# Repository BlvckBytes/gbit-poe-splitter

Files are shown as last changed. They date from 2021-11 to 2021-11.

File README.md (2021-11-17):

# gbit-poe-splitter

Power devices which don't support PoE and fine-adjust the received voltage at the same time. This equipment conforms to the *802.3at* standard, also known as *PoE+*.

⚠️ Use at your own risk and always properly test the product before connecting expensive gear up to it!

## Table of Contents

* [Goals](#goals)
* [The Product](#the-product)
* [Introduction](#introduction)
  * [802\.3af (PoE)](#8023af-poe)
  * [802\.3at (PoE\+)](#8023at-poe)
  * [802\.3bt (Hi\-PoE, PoE\+\+)](#8023bt-hi-poe-poe)
* [Concept](#concept)
* [Features](#features)
  * [Ports](#ports)
  * [Settings](#settings)
  * [Status LEDs](#status-leds)
* [Parts](#parts)
* [Prototyping](#prototyping)
  * [Summary](#summary)

## Goals

* ✅ Small footprint PCB
* ✅ Max budget of 15 Euros
* ✅ Support up to 60V of input
* ✅ Selectable output voltage
* ✅ Selectable PoE class
* ✅ Highest possible current throughput
* ✅ Indication of active type 2
* ✅ DC Output Jack
* ✅ Proper centertap-termination

## The Product

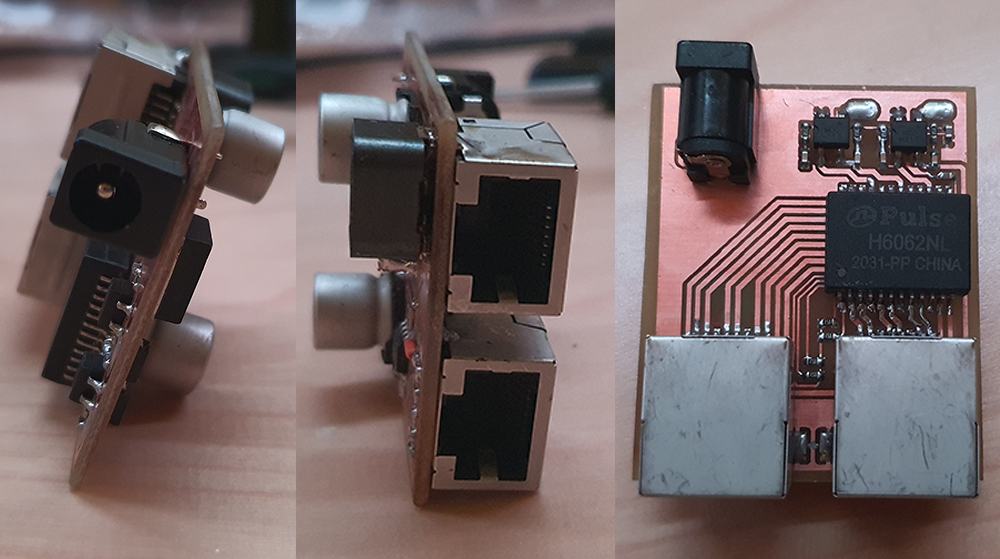
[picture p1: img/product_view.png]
Product View


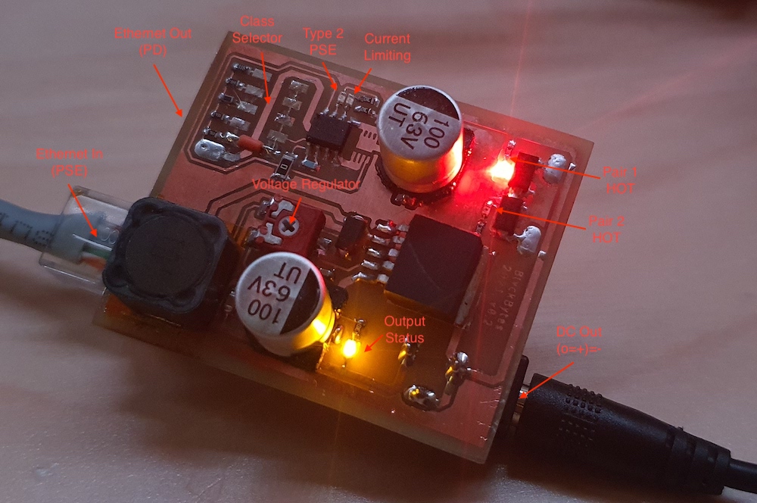
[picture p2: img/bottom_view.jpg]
Bottom View


## Introduction

PoE is short for *Power over Ethernet* and will allow to transmit the needed power for devices on the other end of the CAT-X cable. This is especially of interest for already existing infrastructure, where it's just not economical to run a separate power wire. The only drawbacks are that there's a limit to how much energy can be transmitted and that you might experience a voltage-drop and thus an energy-loss over longer distances of wire.

### 802.3af (PoE)

This standard adds power-delivery to *802.3*, with up to *15.4W* at the output of the power sourcing equipment (PSE), using two twisted-pairs for injection. After calculating the average real world losses over the wire , the consumer only receives around *12.95W* of power. There are also lower power-classes, which are not the default and need to be registered for by the powered device (PD) explicitely.

| Class | Min Power (at PD, [W]) | Max Power (at PD, [W]) |
|:---|:---|:---|
| 0 | 0.44 | 12.95 |
| 1 | 0.44 | 3.84 |
| 2 | 3.84 | 6.49 |
| 3 | 6.49 | 12.95 |

### 802.3at (PoE+)

Since *802.3af* is not sufficient for some standard usecases, *802.3at* bumps it up a notch, while still using only two twisted-pairs. Now, PDs can receive up to *25.5W*, which should be plenty for switches, access-points, VOIP, card-readers and so on and so forth.

| Class | Min Power (at PD, [W]) | Max Power (at PD, [W]) |
|:---|:---|:---|
| 4 | 12.95 | 25.5 |

### 802.3bt (Hi-PoE, PoE++)

In order to meet the higher demand of power in special cases, IEEE came up with this standard at the end of 2018. Instead of two pairs, it uses all four pairs for power delivery, which will allow up to **100 watts**. Power loss gets cut in half, at least in theory. Since this standard requires more expensive technology, it's not covered by this project.

## Concept

There are several [requirements](https://www.ieee802.org/3/poep_study//email/pdf00005.pdf) to the PD, if it wants to consume *802.3at*.

The main component is represented by the [H6062NL](https://eu.mouser.com/ProductDetail/Pulse-Electronics/H6062NL?qs=hlTQ6wBu%252Bnnq8WII%2F92SGQ%3D%3D), which is a signal transformer that supports up to *1000Base-T*. It consits of four individual isolation transformers, which offer a center-tap for power delivery purposes, where one transformer corresponds to one twisted pair, to fully isolate the PD.

In order to support detection, classification, inrush-current limiting and short-circuit protection, I decided on the [TPS2379](https://www.ti.com/lit/ds/symlink/tps2379.pdf?ts=1636211997743&ref_url=https%253A%252F%252Fwww.google.com%252F). It supports up to *1A* of operating current, which should be plenty, and can even be extended using an external mosfet.

To tap the available power from either one of the two pairs, and to handle reverse-polarity situations, two full bridge rectifiers are inserted directly inbetween the transformers and the control-IC. The output voltage will then be fed through a buck-converter, to easily regulate it. [LM2596HV](http://hmsemi.com/downfile/LM2596HV.PDF) seems to be a perfect fit for this job.

### Detection

The PSE constantly pulses a 4-point detection signal on the port in question, which starts out `LOW` and then rises `HIGH` two times. With the known voltage potential, and the measurable current draw, the PSE calculates the inner resistance of the connected PD. It has to `23.75kOhm < R < 26.25kOhm`, to be a valid PoE device.

### Classification

After passing detection, the PD has to specify it's desired power class to the PSE. The PSE sends signals between 14.5V and 20.5V, while the PD removes R_DET from the line and applies R_CLS, in series with a constant 2.5V regulator. This way, the PSE can accurately measure the current flowing through R_CLS, and thus determine the desired class.

After completing both steps successfully, power is activated.

## Features

### Ports

* Ethernet in (from PSE)
* Ethernet out (to non-PD)
* Standard DC-jack to supply power

### Settings

* 5 positions for class 0-4
* Voltage regulation potentiometer

### Status LEDs

* Power available (Yellow)
* Inrush current limiting (Yellow)
* Type 2 active (Yellow)
* Pair 1 & 2 hot (Red)
* Pair 3 & 4 hot (Red)

## Parts

| Part | Description | Shop | Price/Pice | Amount | Total |
|:-----|:---|:-----|:---|:---|:---|
| **Integrated Circuits** |
| H6062NL | Signal Transformer | Mouser | 4.27€ | 1 | 4.27€ |
| TPS2379 | 802.3af PD Interface | Mouser | 2.35€ | 1 | 2.35€ |
| MB1S-TP | Bridge Rectifier | Mouser | 0.26€ | 2 | 0.52€ |
| LM2596HV | [Regulator & aux. Components](https://de.aliexpress.com/item/32916300929.html?spm=a2g0s.9042311.0.0.55414c4dqviJXF) | AliExpress | 1.12€ | 1 | 1.12€ |
| SI7454FDP-T1-RE3 | N-Channel Mosfet | Mouser | 0.69€ | 1 | 0.69€ |
| **Connectors** |
| RJLSE4118101 | RJ45 8P8C Shielded | Mouser | 0.91€ | 2 | 1.82€ |
| PRT-10811 | 5.5mm DC Jack | Mouser | 0.81€ | 1 | 0.81€ |
| **Status LEDs** |
| CRCW060310K0FKTC | 10k Ohm 0603 | Mouser | 0.022€ | 5 | 0.11€ |
| 150060GS75000 | LED Yellow 0603 | Mouser | 0.12€ | 3 | 0.24€ |
| 150060GS75000 | LED Red 0603 | Mouser | 0.12€ | 2 | 0.24€ |
| **Filtering & Termination** |
| RC0603FR-0775RL | 75 Ohm 0603 | Mouser | 0.006€ | 8 | 0.012€ |
| CL10B103KO8NNNC | 10nF 0603 | Mouser | 0.011€ | 4 | 0.044€ |
| C0805C104K8RACAUTO | 100nF 0805 | Mouser | 0.058€ | 1 | 0.058€ |
| CL10C102JB8NNND | 1nF 0603 | Mouser | 0.016€ | 2 | 0.032€ |
| **PoE Class (R_CLS)** |
| RC0603FR-071K27L | 1.27k Ohm 0603 | Mouser | 0.008€ | 1 | 0.008€ |
| CR0603-FX-2430ELF | 243 Ohm 0603 | Mouser | 0.016€ | 1 | 0.016€ |
| ERJ-3EKF1370V | 137 Ohm 0603 | Mouser | 0.014€ | 2 | 0.014€ |
| CR0603-FX-90R9ELF | 90.9 Ohm 0603 | Mouser | 0.013€ | 1 | 0.013€ |
| CR0603-FX-63R4ELF | 63.4 Ohm 0603 | Mouser | 0.013€ | 1 | 0.013€ |
| **R_DEN** |
| RK73H1JTTDD2492F | 24.9k Ohm 0603 | Mouser | 0.01€ | 1 | 0.01€ |
| **Miscellaneous** |
| RK73B1JTTD204J | 200k Ohm 0603 | Mouser | 0.008€ | 1 | 0.008€ |
| GS2M-LTP | Rectifier Diode | Mouser | 0.28€ | 2 | 0.56€ |
| ACP 6-SMD 10K | SMD Trimmer | Reichelt AT | 0.30€ | 1 | 0.30€ |

Total: ~13€

## Prototyping

07.11.2021:

I wanted to check if I could extract power using only the transformer, like some people managed to do online, with no additional logic. After finding an old gigabit-capable router in my basement, I disassembled it and unsoldered one of it's internal transformators ([G4802CG](https://media.digikey.com/pdf/Data%20Sheets/Mentech%20PDFs/G4802CG.pdf)). I also tried one from a 100M model, which didn't work, because they've joined up the centertaps on neighboring coils. The pins were so small that a breakout-board was necessary. This was my test-setup:

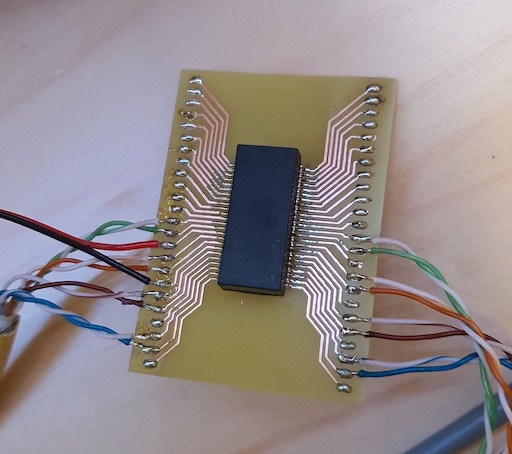
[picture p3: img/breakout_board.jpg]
Breakout-Board


On the left, the PSE is connected, where the power gets extracted, and on the right, it's my laptop (PD). I'm using a `Netgear GS305P`, and nope, it's not directly spitting out power without additional logic. I actually discovered that it pulses a few volts on all ports, no matter if something is connected or not. I guess that's where the PD would use load modulation to register itself and it's desired power-class. Now I'm waiting to receive my mouser-order to continue with this test-setup, until the first prototype is up and working, only then will I create a full PCB-layout.

Just in case you're wondering, here's whats inside the IC, I think it looks wonderful:

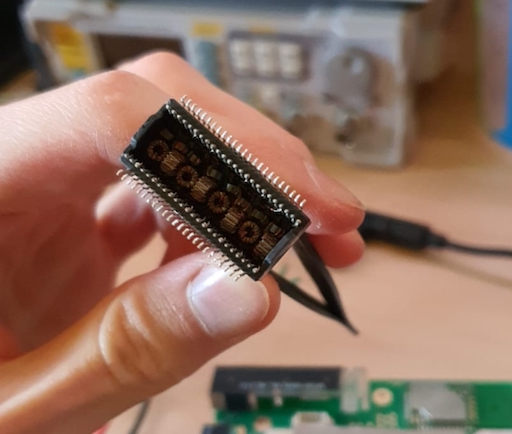
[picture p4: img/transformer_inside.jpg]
Transformer Inside


09.11.2021:

Yesterday and today I finally created all missing footprints and symbols to create the first revision of the schematic. I tried to keep it organized through grouping by functional blocks, as you usually do. Still need to revise it, before I go into routing the board.

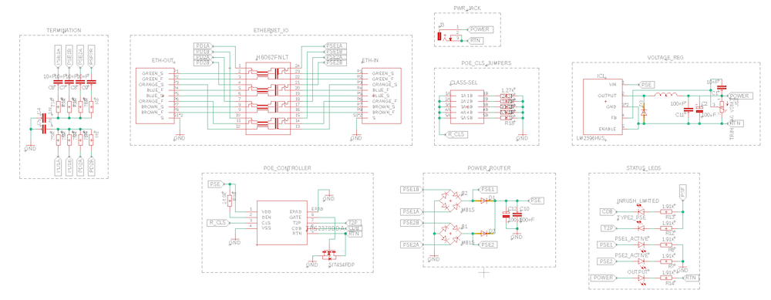
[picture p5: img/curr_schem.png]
Current Schematic


Now that the schematic is done, I started on some small parts of routing. I kinda want to have the ethernet ports on one side of the board next to each other, and the DC jack vis-a-vis. The ethernet signal lines are basically just passed through the transformer, which should be done in a short and "bus-like" fashion.

10.11.2021:

The board is completely routed out now, all airwires have been connected. Looks quite nice so far, I don't think that I can squeeze it any tighter without going down yet another rabbit-hole.

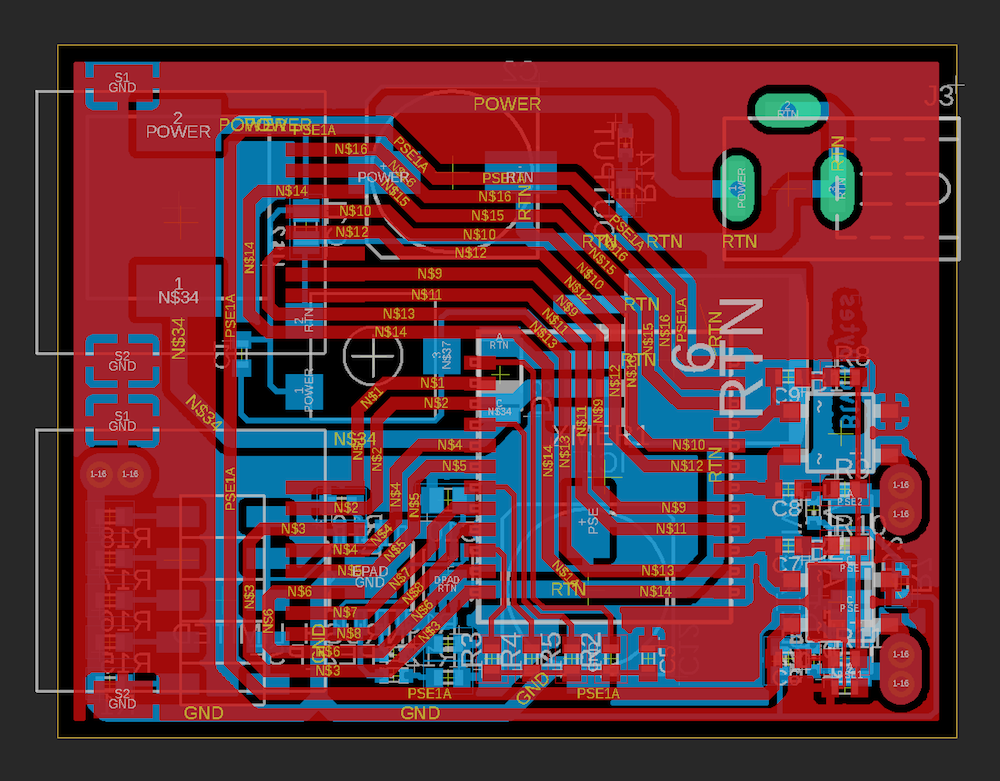
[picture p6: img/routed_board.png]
Routed Board


After correcting other small mistakes, the first physical prototype has been created.

First, I created a double-sided "pouch" out of two overhead projector sheets, having the printed (toner) sides facing together. To block out most tiny holes, I overlayed two sheets of each side. My trusty `HP LaserJet 1200` did a great job again.

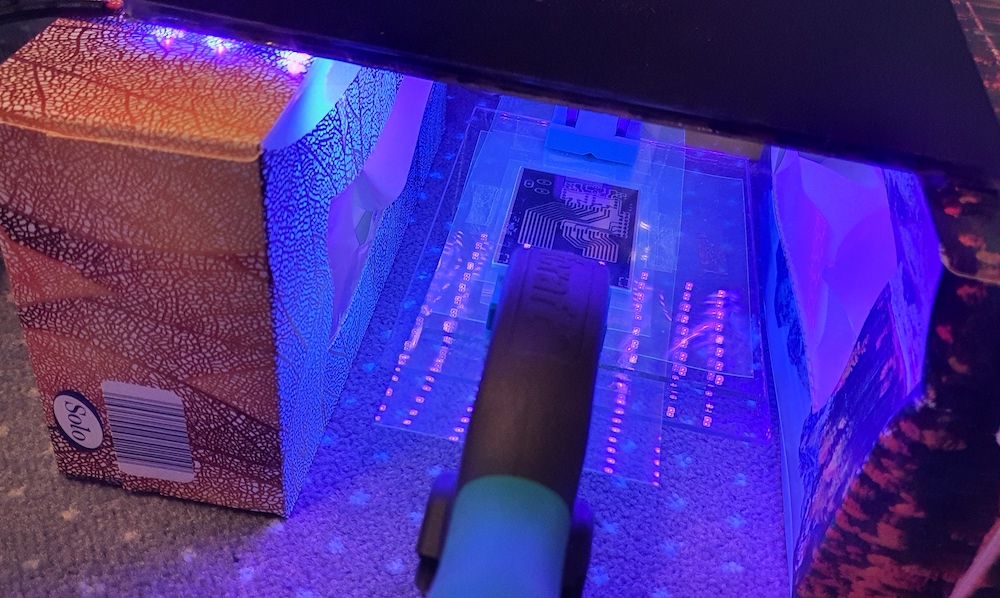
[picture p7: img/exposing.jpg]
Exposing


After exposing, I developed the foto-resist and then etched away unmasked sections using [sodium persulfate](https://solectroshop.com/en/grabado-de-circuito/455-1kg-de-persulfato-de-sodio-pcb-etchant-para-circuitos-impresos.html), while I heated the solution using the exhaust of my computer, ;).

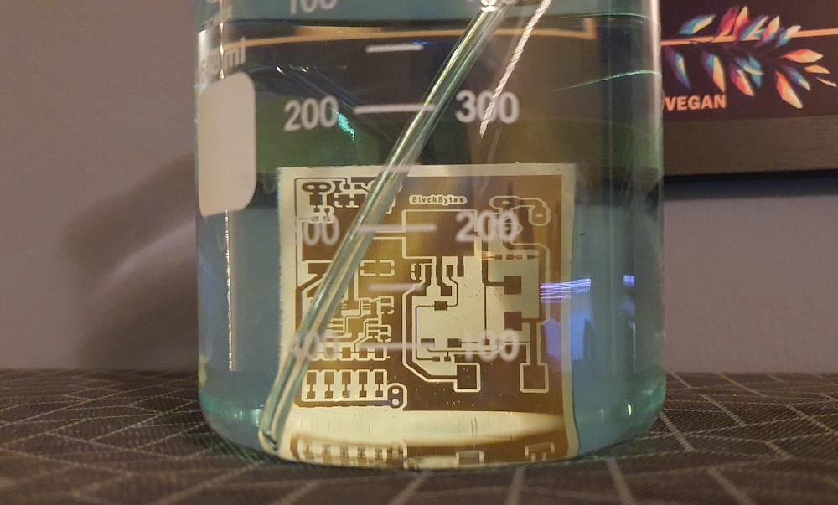
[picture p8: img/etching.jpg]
Etching


Quite pleased with the result, although I still need to continuity-check it using my multimeter.

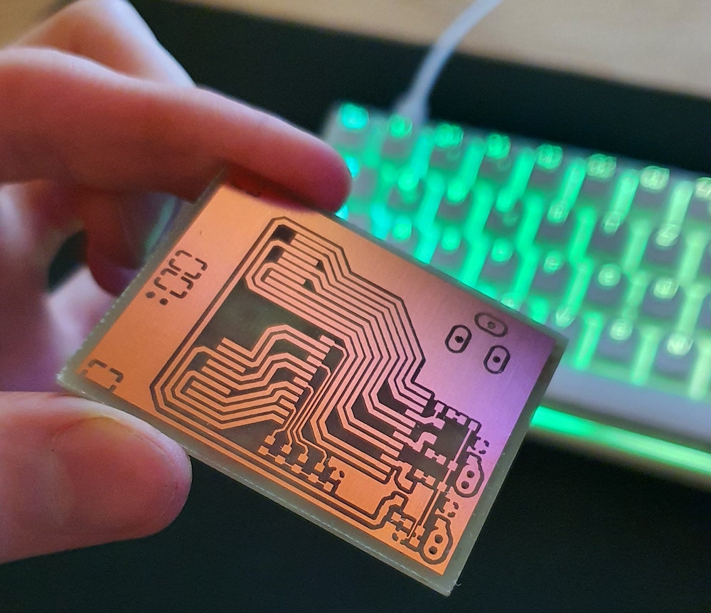
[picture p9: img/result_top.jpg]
Result Top


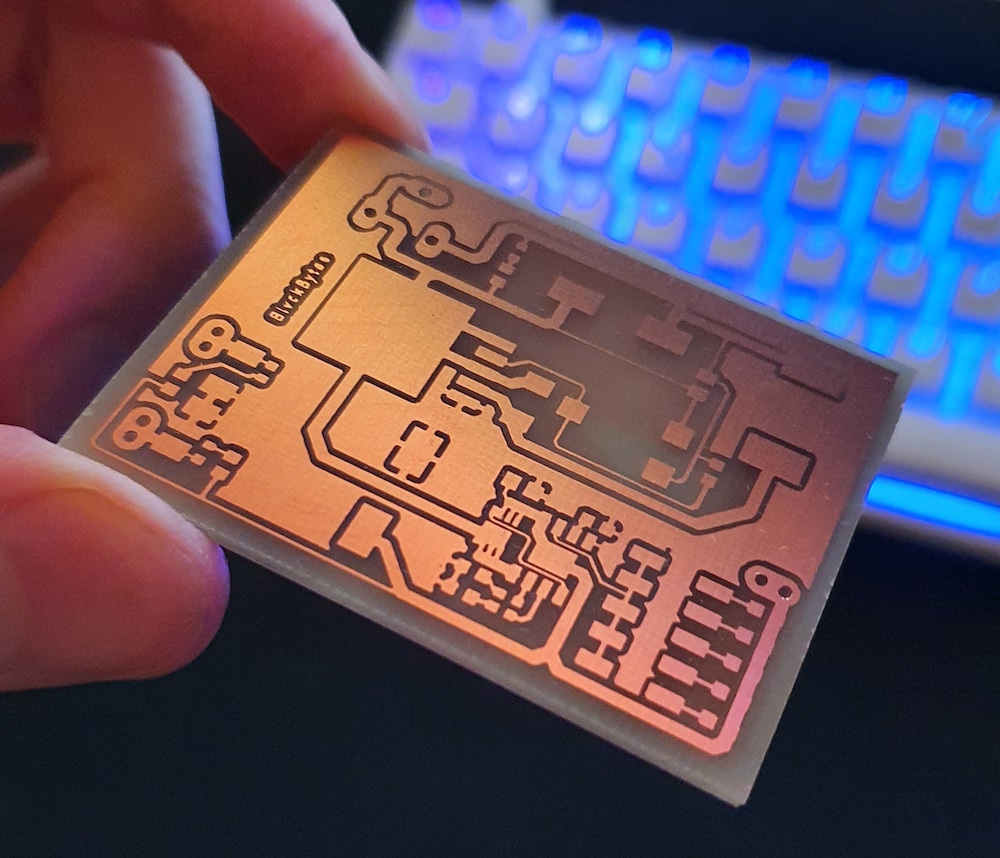
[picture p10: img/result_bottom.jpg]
Result Bottom


Thankfully I managed to only need through-holes for 6 vias and the DC jack. I hate drilling, it's extremely hard to pull off accurately on such a scale. The holes on both sides lined up perfectly tho, I'm extremely happy about that.

The rivets also worked out okay-ish this time, since I'm going easier on them with the tool. It's still far from perfect, but I think it gets the job done.

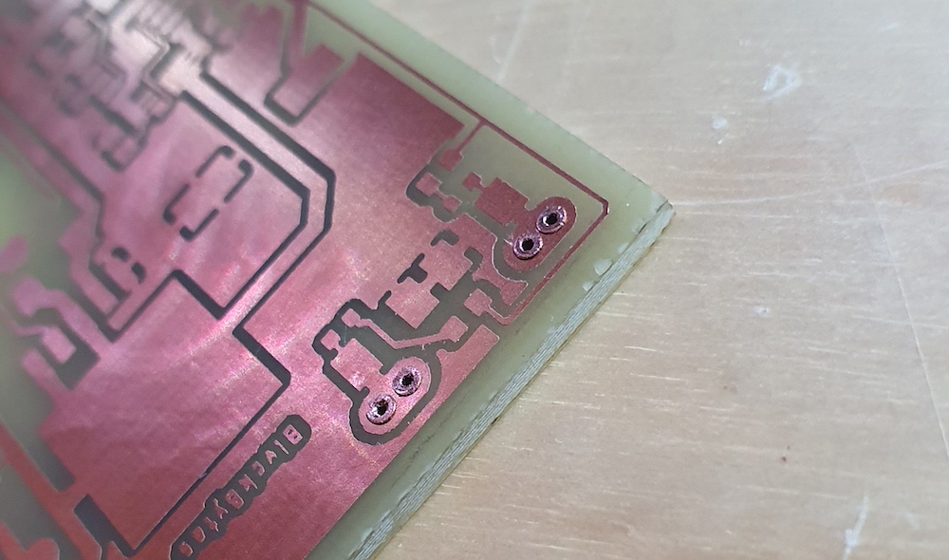
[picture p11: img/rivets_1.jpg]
Rivets 1


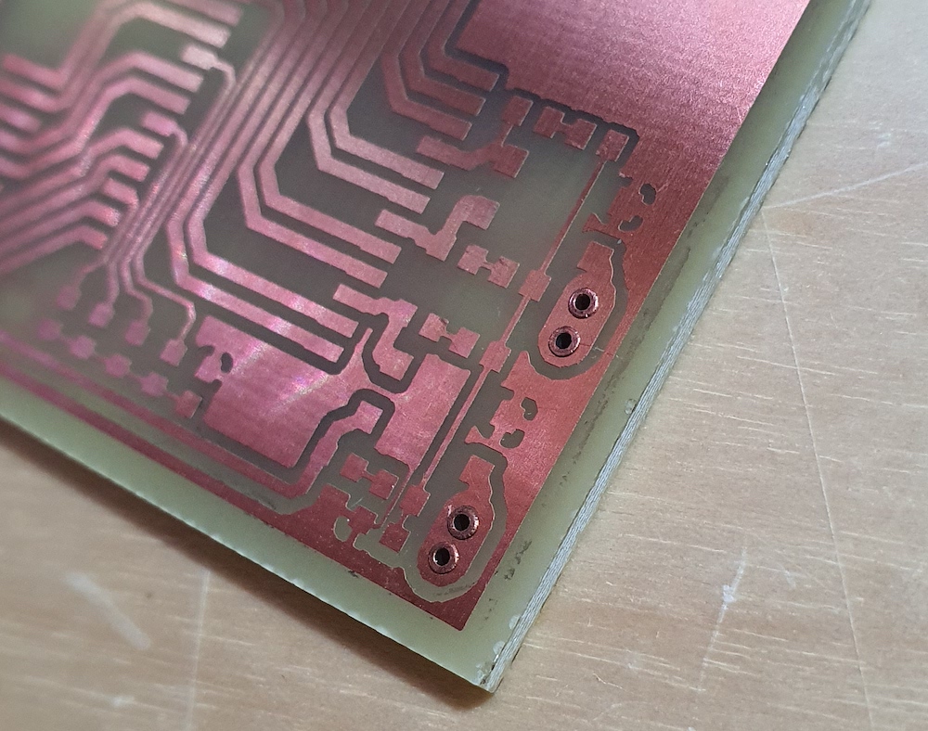
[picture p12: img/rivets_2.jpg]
Rivets 2


13.11.2021:

After soldering all top-layer components, I tested the board for gbit-ethernet passthrough and low power pulse extraction (as it currently is without the controller IC), and everything works as expected.

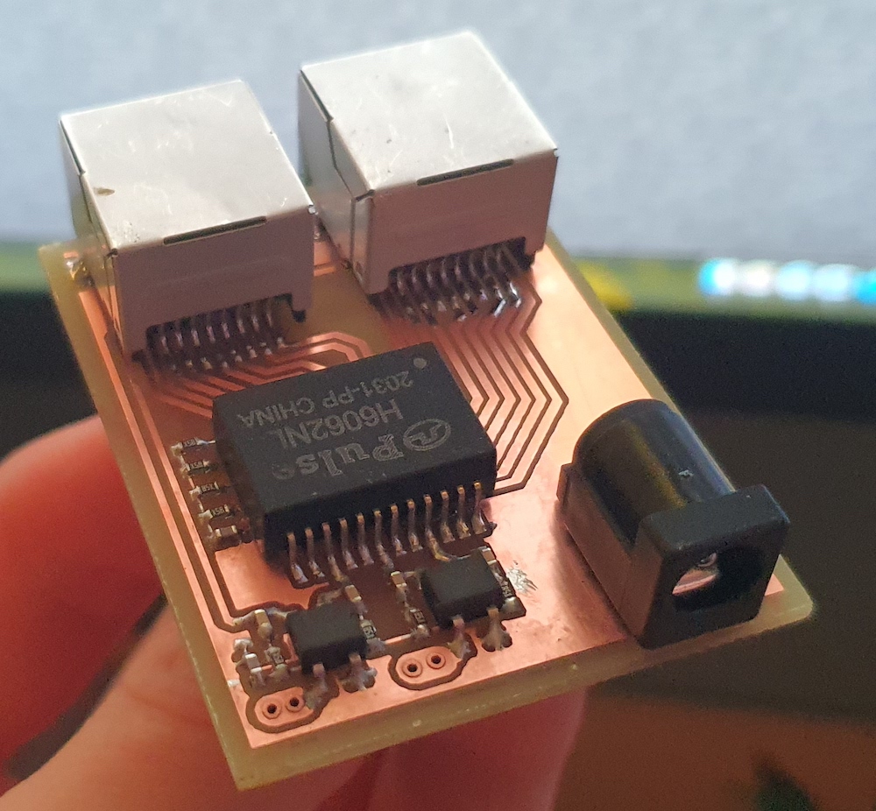
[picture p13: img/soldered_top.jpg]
Soldered Top


### Summary

There have been many things I learned from the first prototype, as this project definitely has it's stumbling blocks...

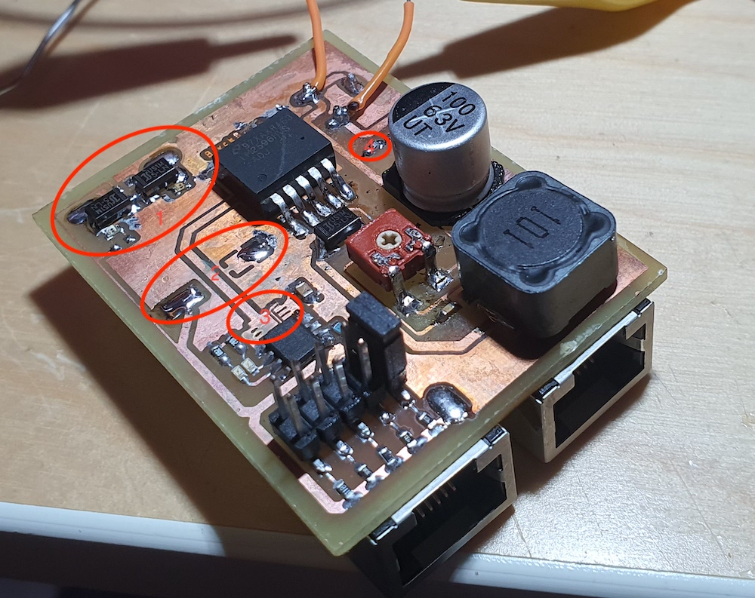
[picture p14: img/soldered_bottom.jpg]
Soldered Bottom


1. The pair-indicator LEDs cannot be directly connected, as they change the resistive reading of the PSE, which therefore cannot act properly. Instead of wiring them to ground, I need to connect them to the PoE-IC's return pin.
2. Same issue as with the LEDs occurrs with the input smoothing cap. Also needs ground as return.
3. The external mosfet's package is extremely cumbersome for DIY, change that.
4. LEDs need a higher resistance, as 1.9kOhm just doesn't cut it. They almost burn at 40+V.

Everything else seems to be okay so far, just that with a small load of - for example - 1kOhm, the PSE disconnects power when the current-draw drops below around 10mA. Would be great if there was a fallback load, so that power regulation is possible down to a few volts.

16.11.2021:

After taking a short break from this project, I now fixed the issues within my layout and managed to squeeze things even tighter, shaving off a few more millimeters of length. The voltage regulation also seems to work perfectly without a load, the previous potentiometer was melted from all the hot air I used on the board, and the input smoothing cap probably also added some further power detection possibilities for the PSE. All up and running now.

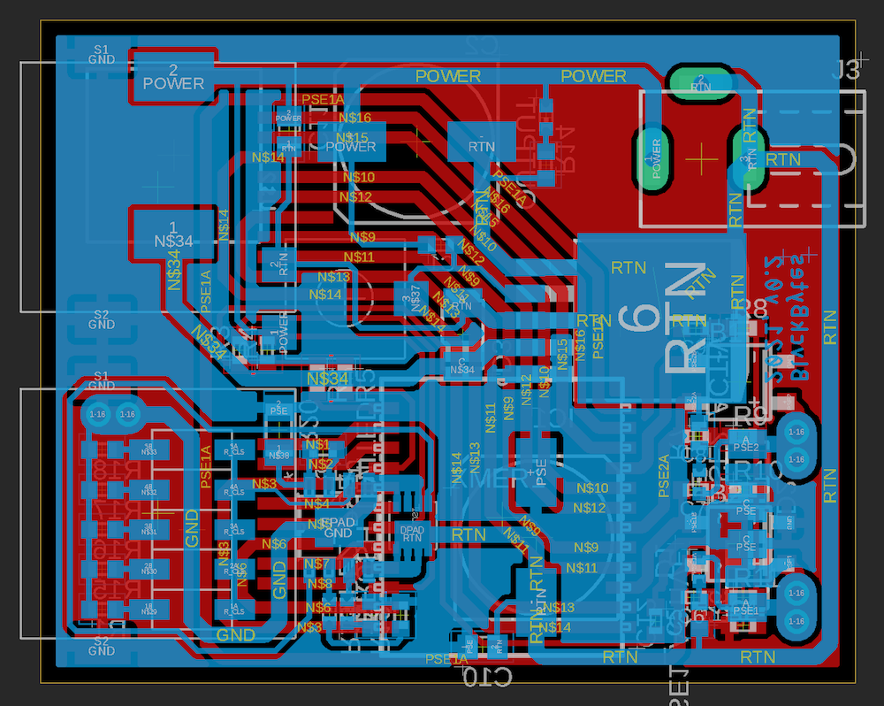
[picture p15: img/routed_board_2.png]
Routed Board


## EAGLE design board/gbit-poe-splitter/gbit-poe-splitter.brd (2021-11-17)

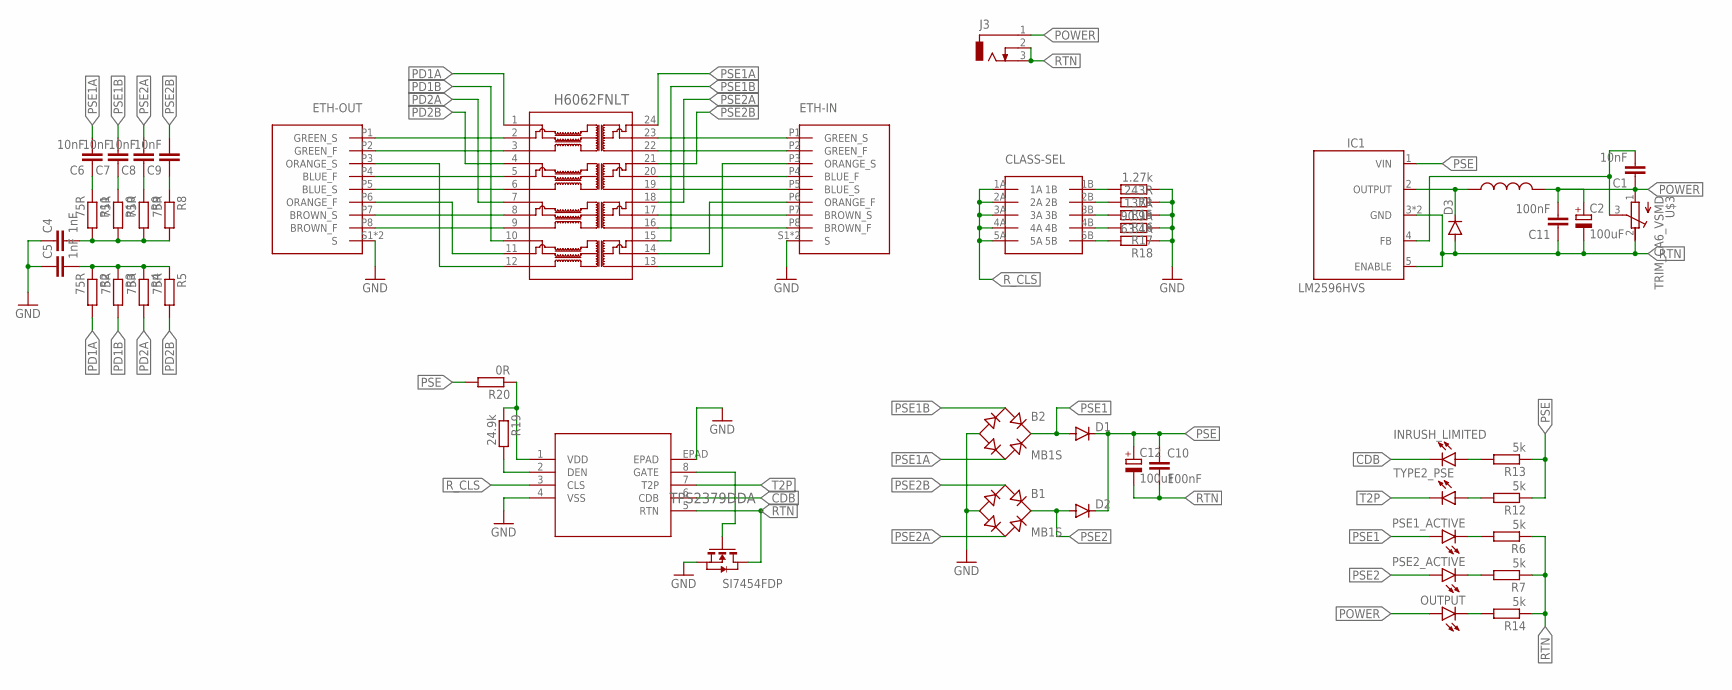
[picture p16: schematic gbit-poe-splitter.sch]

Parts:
B1, B2: MB1S; SOIC-4
C1, C6, C7, C8, C9: 10nF; C0603K
C2, C12: 100uF; 153CLV-1012
C4, C5: 1nF; C0603K
C10, C11: 100nF; C0805
CLASS-SEL: 54202-T0803AB01LF
D1, D2, D3: DIODE-DO-214AC; DO-214AC
ETH-IN: RJLSE-4X1XX-01
ETH-OUT: RJLSE-4X1XX-01
IC1: LM2596HVS; TO263-5
INRUSH_LIMITED: LEDCHIPLED_0603; CHIPLED_0603
J3: DCJ0303
OUTPUT: LEDCHIPLED_0603; CHIPLED_0603
PSE1_ACTIVE, PSE2_ACTIVE: LEDCHIPLED_0603; CHIPLED_0603
R1: 1.27k; R0603
R2, R3, R4, R5, R8, R9, R10, R11: 75R; R0603
R6, R7, R12, R13, R14: 5k; R0603
R15: 243R; R0603
R16: 137R; R0603
R17: 90.9R; R0603
R18: 63.4R; R0603
R19: 24.9k; R0603
R20: 0R; R1206
TYPE2_PSE: LEDCHIPLED_0603; CHIPLED_0603
U1: TPS2379DDA; DDA8_3P1X2P4_TEX
U$1: SI7454FDP; POWERPAK-SO-8
U$2: INDUCTOR-SMD7070; INDUCTOR-SMD
U$3: TRIM_CA6_VSMD
XMER1: H6062FNLT; H6062FNLT_PUL

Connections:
CDB: INRUSH_LIMITED.C, U1.6 (CDB)
GND: B1.-, B2.-, C4.1, C5.1, ETH-IN.S1 (S), ETH-IN.S2 (S), ETH-OUT.S1 (S), ETH-OUT.S2 (S), R1.1, R15.1, R16.1, R17.1, R18.1, U1.4 (VSS), U1.EPAD, U$1.S1 (S), U$1.S2 (S), U$1.S3 (S)
unnamed: ETH-OUT.P1 (GREEN_S), XMER1.2
unnamed: ETH-OUT.P2 (GREEN_F), XMER1.3
unnamed: ETH-OUT.P3 (ORANGE_S), XMER1.12
unnamed: ETH-OUT.P4 (BLUE_F), XMER1.5
unnamed: ETH-OUT.P5 (BLUE_S), XMER1.6
unnamed: ETH-OUT.P6 (ORANGE_F), XMER1.11
unnamed: ETH-OUT.P7 (BROWN_S), XMER1.8
unnamed: ETH-OUT.P8 (BROWN_F), XMER1.9
unnamed: ETH-IN.P7 (BROWN_S), XMER1.17
unnamed: ETH-IN.P4 (BLUE_F), XMER1.20
unnamed: ETH-IN.P8 (BROWN_F), XMER1.16
unnamed: ETH-IN.P5 (BLUE_S), XMER1.19
unnamed: ETH-IN.P6 (ORANGE_F), XMER1.14
unnamed: ETH-IN.P3 (ORANGE_S), XMER1.13
unnamed: ETH-IN.P2 (GREEN_F), XMER1.22
unnamed: ETH-IN.P1 (GREEN_S), XMER1.23
unnamed: C5.2, R2.1, R3.1, R4.1, R5.1
unnamed: C4.2, R8.2, R9.2, R10.2, R11.2
unnamed: C6.1, R11.1
unnamed: C7.1, R10.1
unnamed: C8.1, R9.1
unnamed: C9.1, R8.1
unnamed: PSE1_ACTIVE.C, R6.2
unnamed: PSE2_ACTIVE.C, R7.2
unnamed: R12.2, TYPE2_PSE.A
unnamed: INRUSH_LIMITED.A, R13.2
unnamed: OUTPUT.C, R14.2
unnamed: CLASS-SEL.1B, R1.2
unnamed: CLASS-SEL.2B, R15.2
unnamed: CLASS-SEL.3B, R16.2
unnamed: CLASS-SEL.4B, R17.2
unnamed: CLASS-SEL.5B, R18.2
unnamed: D3.C, IC1.2 (OUTPUT), U$2.1
unnamed: U1.8 (GATE), U$1.G
unnamed: R19.2, U1.2 (DEN)
unnamed: C1.2, IC1.4 (FB), U$3.3 (S)
unnamed: R19.1, R20.1, U1.1 (VDD)
PD1A: R2.2, XMER1.1
PD1B: R3.2, XMER1.10
PD2A: R4.2, XMER1.7
PD2B: R5.2, XMER1.4
POWER: C1.1, C2.+, C11.2, J3.1, OUTPUT.A, U$2.2, U$3.1 (A)
PSE: C10.1, C12.+, D1.C, D2.C, IC1.1 (VIN), R12.1, R13.1, R20.2
PSE1: B2.+, D1.A, PSE1_ACTIVE.A
PSE1A: B2.~2 (AC2), C6.2, XMER1.24
PSE1B: B2.~1 (AC1), C7.2, XMER1.15
PSE2: B1.+, D2.A, PSE2_ACTIVE.A
PSE2A: B1.~2 (AC2), C8.2, XMER1.18
PSE2B: B1.~1 (AC1), C9.2, XMER1.21
RTN: C2.-, C10.2, C11.1, C12.-, D3.A, IC1.3 (GND), IC1.5 (ENABLE), IC1.6 (GND), J3.2, J3.3, R6.1, R7.1, R14.1, U1.5 (RTN), U$1.D1 (D), U$1.D2 (D), U$1.D3 (D), U$1.D4 (D), U$1.DPAD (D), U$3.2 (E)
R_CLS: CLASS-SEL.1A, CLASS-SEL.2A, CLASS-SEL.3A, CLASS-SEL.4A, CLASS-SEL.5A, U1.3 (CLS)
T2P: TYPE2_PSE.C, U1.7 (T2P)

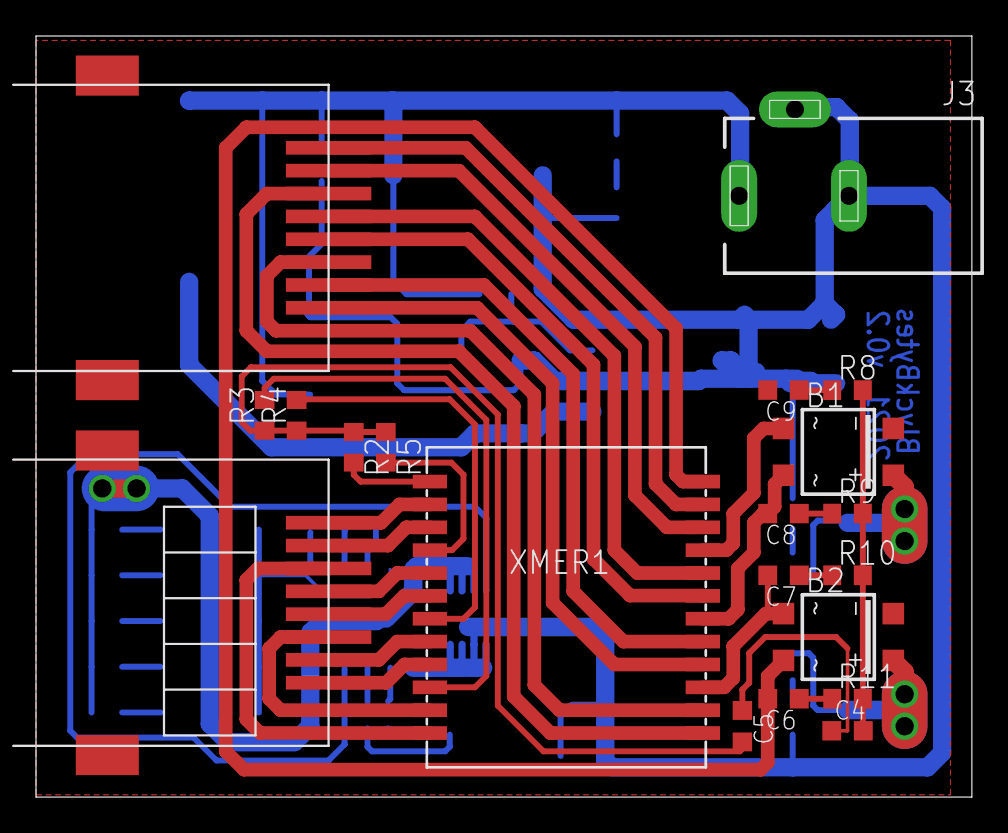
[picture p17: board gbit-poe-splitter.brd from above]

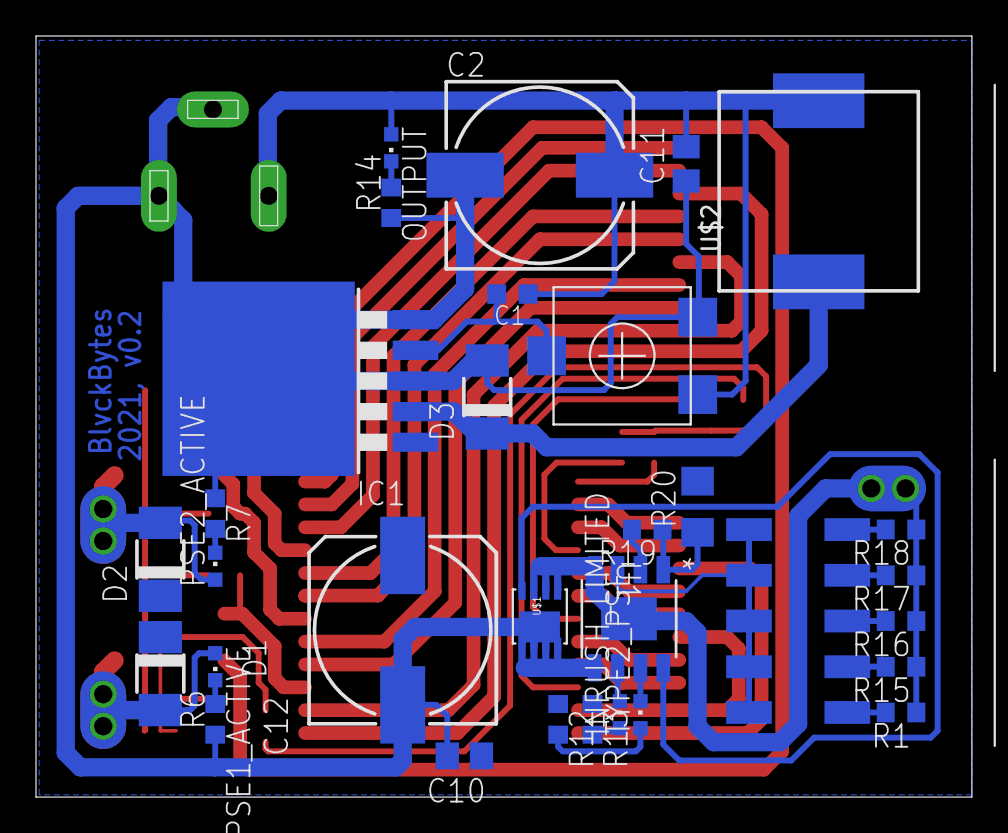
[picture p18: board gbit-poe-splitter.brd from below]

Board: 2 copper layers, 52.0 x 42.3 mm, 51 parts (31 on the bottom side), 54 nets.

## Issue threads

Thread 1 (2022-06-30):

Help with different PoE controller.

Daniel-bug, 2022-06-30:
Hi Philip,
my name is Daniel and I would like to ask you for your help.
My friends and I are developing a board and we want to have an active PoE.
After doing some research I have found your project on GitHub, which is amazing btw. So I basically wanted to copy your board, only using different voltage regulators (one simple 5V and one 3,3V).
But then I ran into the problem with the PoE controller TPS2379 being completely sold out everywhere, with availability maybe next year in may :(
So I searched for different option and I found TPS2375D also from TI:
[TPS237x: IEEE 802.3af PoE Powered Device Controllers datasheet (Rev. B) (ti.com)](https://www.ti.com/lit/ds/symlink/tps2375.pdf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)

After reading datasheets for both controllers I thought that I can basically switch them with just a few changes (no mosfet, different class resistors, etc...). So I proceed to make a schematic and then routing a board.

After soldering everything in place (which was really pain for all 0603 SMDs :D) my board is not working.
I do not rule out that I may have a short circuit on the board that I did not detect. Or that I overheated a component while repairing the contacts. But I would still like to know the opinion of an experienced person like you on whether my schematic is correct before ordering a professional PCB with green varnish.

Could you please take a quick look at my schematic (in attachment) if it makes sense to you or if I overlooked something? Or if you can direct me on how to troubleshoot my board, like what I should measure where. You talked about parasitic resistance messing with detection.

A would be really glad for any help.
Thank you for your work

[Schematic_PoE splitter githubu with different controller_2022-06-27.pdf](https://github.com/BlvckBytes/gbit-poe-splitter/files/9020907/Schematic_PoE.splitter.githubu.with.different.controller_2022-06-27.pdf)

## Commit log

2021-11-08 Created and gathered custom libraries for parts, created base schematic file
    [gbit-poe-splitter.sch]
2021-11-09 Created first revision of the full schematic
    [gbit-poe-splitter.brd]
2021-11-09 Began the routing process
    [gbit-poe-splitter.brd, gbit-poe-splitter.sch]
2021-11-09 Routed top side of the board completely
    [gbit-poe-splitter.brd]
2021-11-10 Completed board layout
    [gbit-poe-splitter.brd, gbit-poe-splitter.sch]
2021-11-10 Fixed jack orientation, font and keepouts
    [gbit-poe-splitter.brd, gbit-poe-splitter.sch]
2021-11-10 Documented first physical prototype
    [gbit-poe-splitter.brd]
2021-11-10 Documented regulator testing
2021-11-12 Fixed horrible ethernet pin swap
    [gbit-poe-splitter.brd, gbit-poe-splitter.sch]
2021-11-12 Updated schematic
2021-11-13 Added finished top image
    [gbit-poe-splitter.brd]
2021-11-13 Wrote first prototype summary and added partial fixes to layout
    [gbit-poe-splitter.brd, gbit-poe-splitter.sch]
2021-11-16 Fixed layout issues
    [gbit-poe-splitter.brd, gbit-poe-splitter.sch]
2021-11-16 Fixed board edge
    [gbit-poe-splitter.brd]
2021-11-17 Added finished product images
    [gbit-poe-splitter.brd]

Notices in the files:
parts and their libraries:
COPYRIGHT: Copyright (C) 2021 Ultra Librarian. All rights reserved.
